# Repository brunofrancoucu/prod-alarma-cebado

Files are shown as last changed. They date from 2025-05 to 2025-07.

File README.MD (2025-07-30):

# Consigna
A nivel mundial, cerca de 100 millones de personas sufren de
deshidratación anualmente. Eso equivale a 3 personas por segundo!
Es nuestro deber recordar a la gente a mantenerse hidratada!

Objetivo: Hacer una alarma para tomar mate. Deben diseñar el esquemático y PCB (en KiCad), partiendo del circuito
dispuesto, y generar una bill of materials (BOM) completa.
# kicad - Esquematico y layout
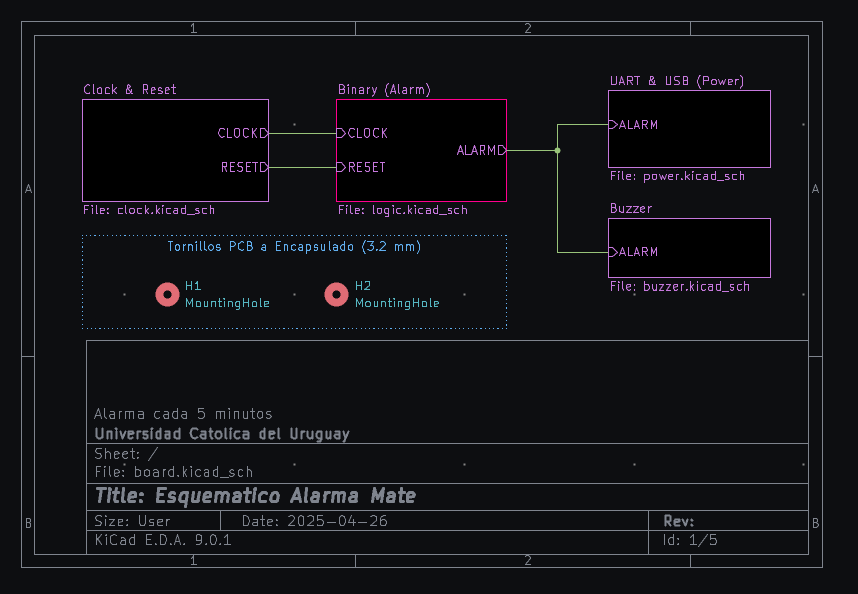
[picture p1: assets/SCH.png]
Stitching Capacitor

Proceso de diseno placa conexiones electricas entre componentes, alineado de componentes, soldadura y manejo en gral, medición de señales, eventuales hotfixes. 
[consideraciones](/board/README.MD), [calculos](/board/README.MD#calculos), [BOM](/BOM.html)
# Autodesk Inventor - Encapsulado
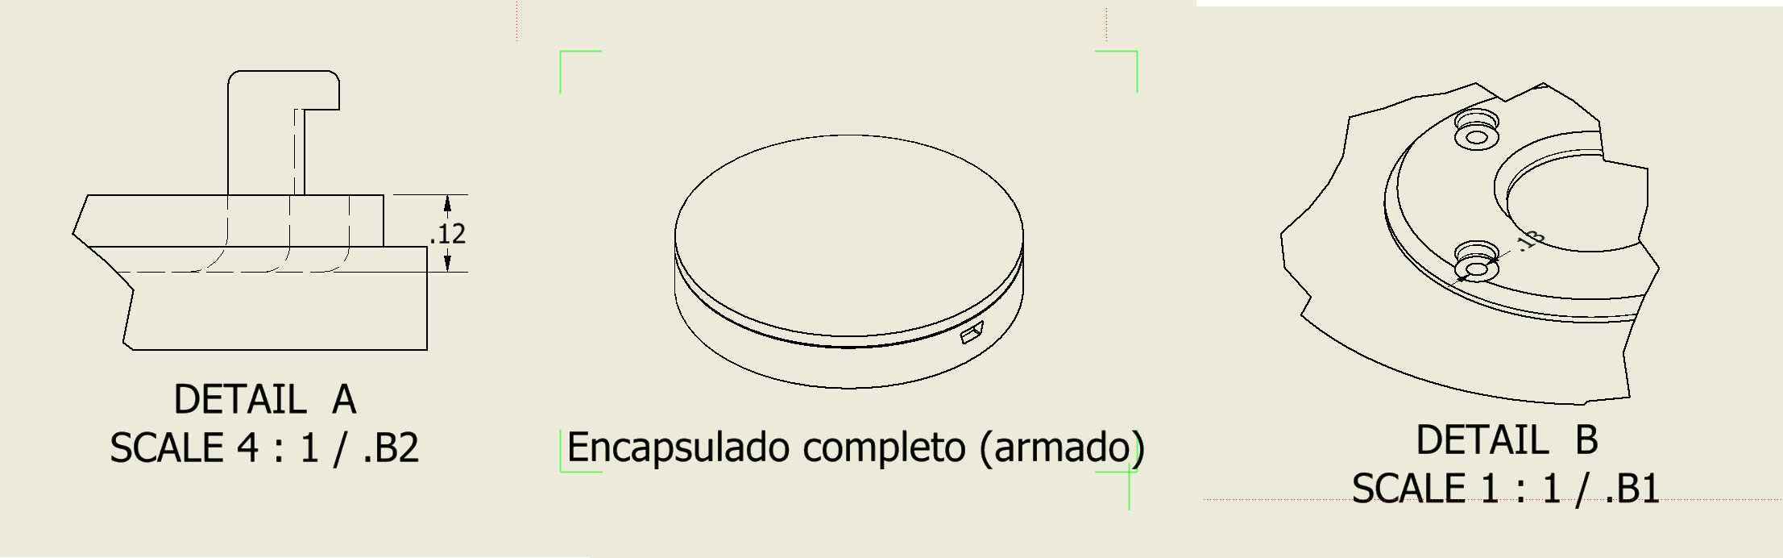
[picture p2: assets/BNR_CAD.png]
Int

Proceso de diseno del envolvente plastico
[consideraciones](/enclosure/README.md#consideraciones-housingipt)

# Producto Final
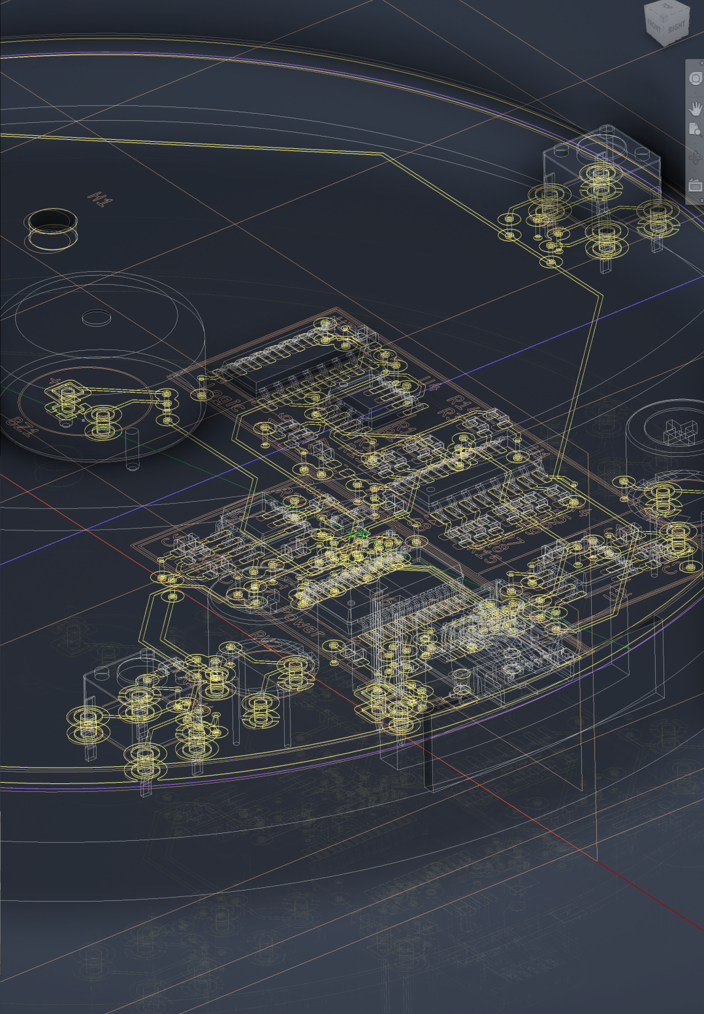
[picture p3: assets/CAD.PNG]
Foto


Feedback:
- Contra-peso [return force](https://www.digikey.com/en/products/detail/same-sky-formerly-cui-devices/TS02-66-90-BK-260-SCR-D/15634305) (btn push)
- USB-c
- Bateria (Conexion a placa)

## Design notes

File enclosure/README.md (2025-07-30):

Int

## Consideraciones `housing.ipt`
- Grosor 1.6 mm +-10% [4-layer PCB](https://www.pcbway.com/multi-layer-laminated-structure.html)
- Conector Ancho 6.9 mm, Alto 3.1 mm [USB](https://www.digikey.com/en/products/detail/same-sky-formerly-cui-devices/TS02-66-90-BK-260-SCR-D/15634305)
- Patas TH 0.5 mm [Buzzer](https://www.digikey.com/en/products/detail/soberton-inc/GT-0905A/1245335)
- Push travel 0.25 mm, Altura 9.0 mm [Actuador](https://www.digikey.com/en/products/detail/same-sky-formerly-cui-devices/TS02-66-90-BK-260-SCR-D/15634305)
- Peso de Plate, >0.2 N (x3) [Return Force](https://www.digikey.com/en/products/detail/same-sky-formerly-cui-devices/TS02-66-90-BK-260-SCR-D/15634305)

## Constrains de Altura
- Dado boton push de 9.0 mm (desde PCB)
- Plate con 3.0 mm (desde cara interior)
- Altura desde PCB del `housing` 6.0 mm 
- 2.0 mm enganche (riel) - 0.1 mm margen (impresion) - 0.2 mm push travel
- `housing` inferior, 3.0 mm (hasta PCB) + 1.6 mm PCB

## TODO
-Invertir enganche `plate` con `housing` (no expone interior en derrame)

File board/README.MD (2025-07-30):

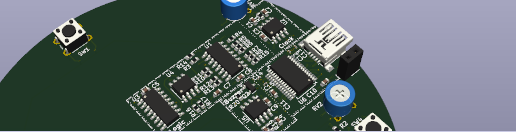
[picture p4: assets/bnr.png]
Int


# Ruteo de alta frecuencia con coupling a GND Y PWR
Par diferencial de alta frecuencia por multiples capas, respetando la impedancia el return path sera por PWR (debido a stack up intermedio de GND PWR y no GND GND), por ello utilizar capacitor en puntos de entrada (source) y salida (exit) (split boundary)

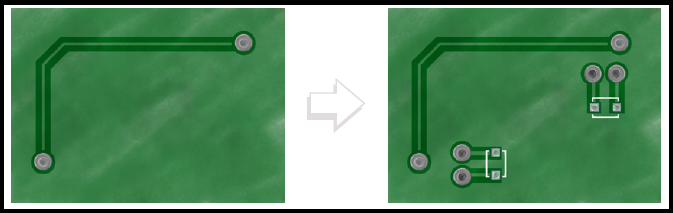
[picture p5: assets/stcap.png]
Stitching Capacitor


### Stitching capacitor:
[ref1](https://www.asset-intertech.com/wp-content/uploads/2020/05/6a01348365b3a6970c01b8d06c22f7970c-pi.jpg), [ref2](https://www.protoexpress.com/blog/wp-content/uploads/2020/05/28.png)
Valores normales para el stitching capacitor ronda los, 10nF and 100nF [src](https://www.protoexpress.com/blog/best-high-speed-pcb-routing-practices/)
Evitar: "If that plane is cut, the return current must detour—often radiating or coupling into other nets—and you’ll get reflections, EMI, and extra crosstalk" - gpt

# Calculos:
### Par diferencial:
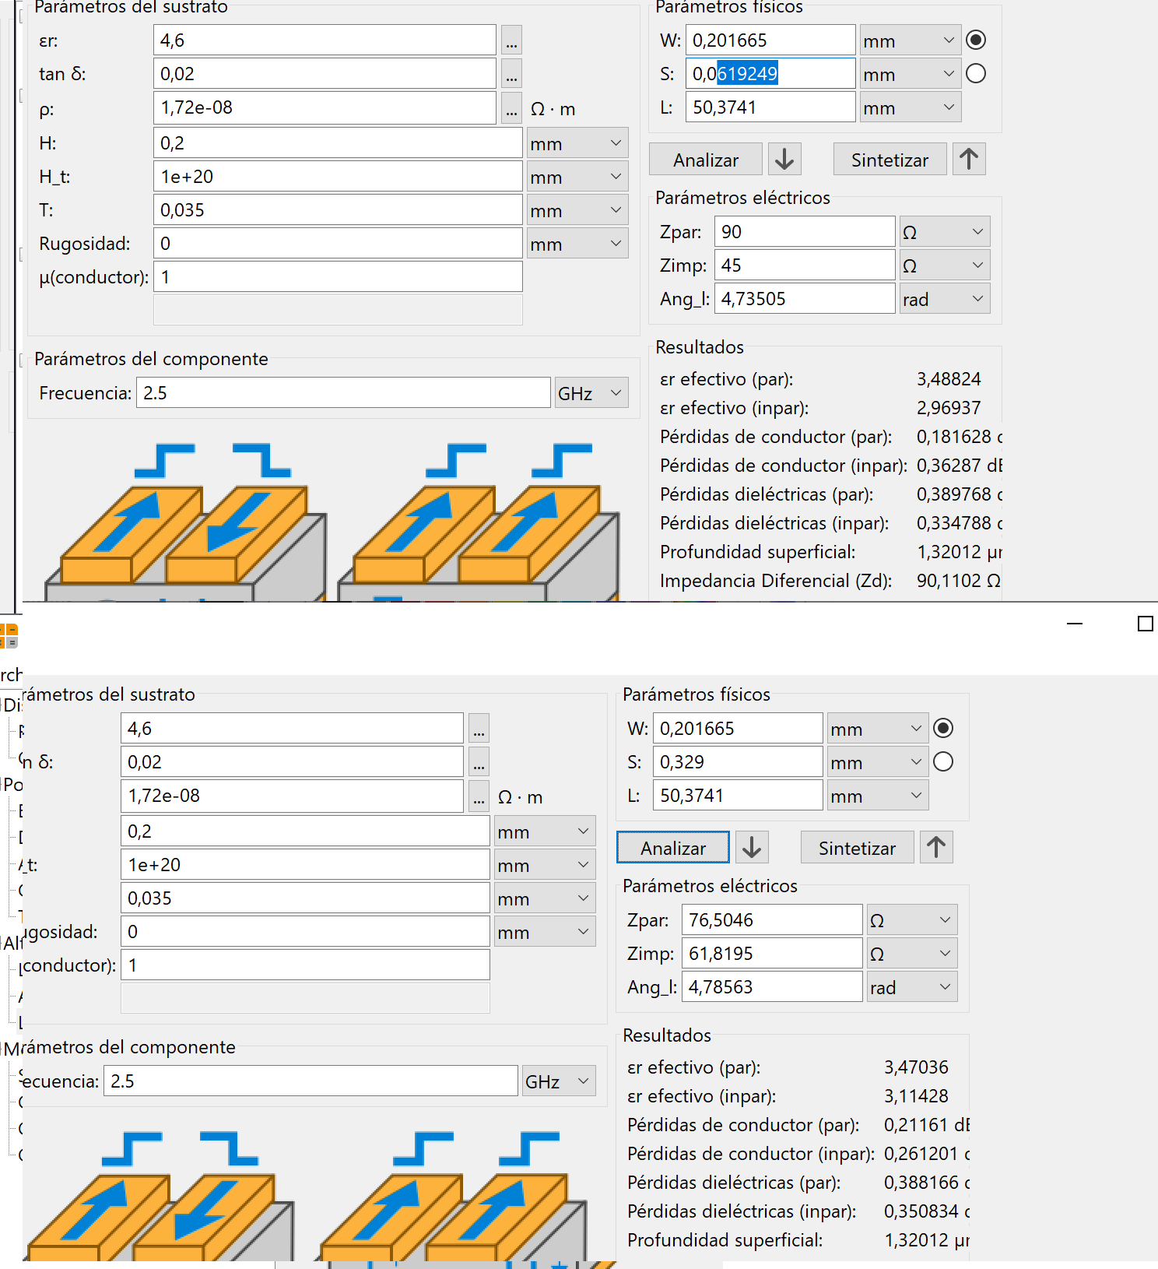
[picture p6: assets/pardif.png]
pardif

Z0: 90ohms +-15%
w: εᵣ 4.6 7628 prepreg FR-4 glass-epoxy laminate [ref](https://jlcpcb.com/capabilities/pcb-capabilities)
h: 0.2mm
Ancho pista: 0.202 mm - separacion pista recomendada: 0.062 mm, maxima: 0.329 mm

### Stitching capacitor, "capacitancia ideal":
Frequencia usb 3.0: 2.5 Ghz (medible con el "rise time" de la señal), entonces, para un Zdiff de 90 ohmios el Zbridge resulta 9 ohmios, capacitancia minima: 7.1 pF
- 100 nF 0402 or 0201	for low-frequency return (10 kHz – 100 MHz)	
- 1 nF 0201	covers 100 MHz – 1 GHz
- 100 pF 0201	covers 1 GHz – 3.5+ GHz (✔️ Recomendable)

Nos aseguramos: effective throughput (bit errors), calidad de señal compliance al USB.

# Complemento

### Recomendacion (plano de referencia limpio): SIG, GND, GND, (SIG + PWR)
Objetivo / desafio: mantener bajo cross talk con un coupling corto / cercano (usando PWR como plano de referencia)

### Otras alternativas:
- GND temporal en PWR (capa 3), justo arriba de par diferencial en la 4ta capa (SIG).
- Rutearlo por arriba.

# TODO
- Bateria Litio recargable
- Entrada USB-C
- Comunicacion puerto UART (notificacion escritorio)

## Gerbers
`File > Export > Fabrication Outputs > Gerbers`
1. `Generate Drill Files...` Gerber X2
2. RUN DRC...
3. Plot
4. Verificar en `Gerber View`

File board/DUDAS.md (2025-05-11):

# Dudas
## Que pasa si una corriente de PWR pasa por el mismo lugar del coupling de HF en PWR?
"The stitching capacitor gives the high-frequency return current a tiny, low-inductance bridge to ground while remaining invisible to the DC and low-frequency load currents on the power plane. Both currents can coexist on the same copper without interfering, provided you keep the plane wide and the decoupling network healthy"
superimpose - no problema, diferentes frequencias

## Como fluye la corriente de retorno si el capacitor bloquea DC?
appears as one continuous copper sheet plane
It’s not for power—it’s for fields
small capacitor’s reactance - planes shorted together
Because the capacitor sits directly beneath the pair and is very low-inductance, the loop area stays tiny and the differential-pair sees a continuous impedance environment.

source: https://www.protoexpress.com/blog/best-high-speed-pcb-routing-practices/

## Averiguar si podemos uasr un capacitor (menor inductancia) 0402 o ... 0201 (actual: protoexpress, 100nF)
"The best high-speed performances are usually accomplished if the component’s width is close to the track width. This will lower the impedance matching issues between the track and the component pad."
- protoexpress (11. Choose ...)
ideal: 100pF 0201

The differential pair itself doesn't require a ground, as it relies on the signal difference between the two traces, not a shared reference to ground. howeber

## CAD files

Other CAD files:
enclosure/Assembly.dwg
enclosure/OldVersions/Assembly.0001.dwg
enclosure/Assembly.iam
enclosure/OldVersions/Assembly.0002.iam
enclosure/OldVersions/housing.0010.ipt
enclosure/OldVersions/plate.0002.ipt
enclosure/board/board/Buzzer_15x7.5RM7.6.ipt
enclosure/board/board/C_0201_0603Metric.ipt
enclosure/board/board/C_0603_1608Metric.ipt
enclosure/board/board/OldVersions/pcb_board.0002.iam
enclosure/board/board/PinSocket_1x02_P2.54mm_Vertical.ipt
enclosure/board/board/Potentiometer_Bourns_3339P_Vertical.ipt
enclosure/board/board/R_0603_1608Metric.ipt
enclosure/board/board/SO-16_3.9x9.9mm_P1.27mm.ipt
enclosure/board/board/SOIC-8_3.9x4.9mm_P1.27mm.ipt
enclosure/board/board/SOT-23.ipt
enclosure/board/board/SSOP-28_5.3x10.2mm_P0.65mm.ipt
enclosure/board/board/SW_PUSH_6mm_H9.5mm.ipt
enclosure/board/board/USB_Mini-B_Lumberg_2486_01_Horizontal.ipt
enclosure/board/board/board.iam
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

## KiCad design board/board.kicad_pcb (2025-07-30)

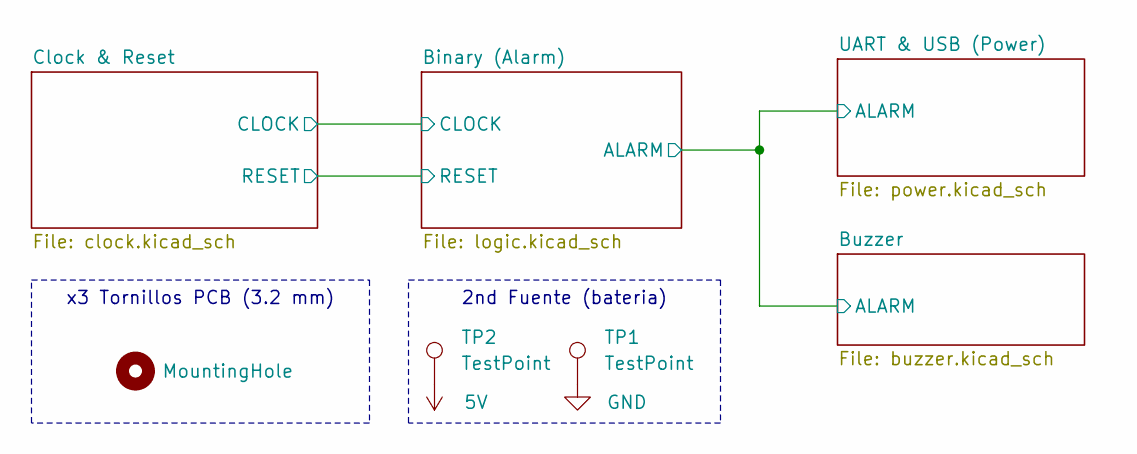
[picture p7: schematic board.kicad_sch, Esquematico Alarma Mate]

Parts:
H1: MountingHole; MountingHole_3.2mm_M3
TP1: TestPoint; TestPoint_THTPad_2.0x2.0mm_Drill1.0mm
TP2: TestPoint; TestPoint_THTPad_D2.0mm_Drill1.0mm

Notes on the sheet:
2nd Fuente (bateria)
x3 Tornillos PCB (3.2 mm)

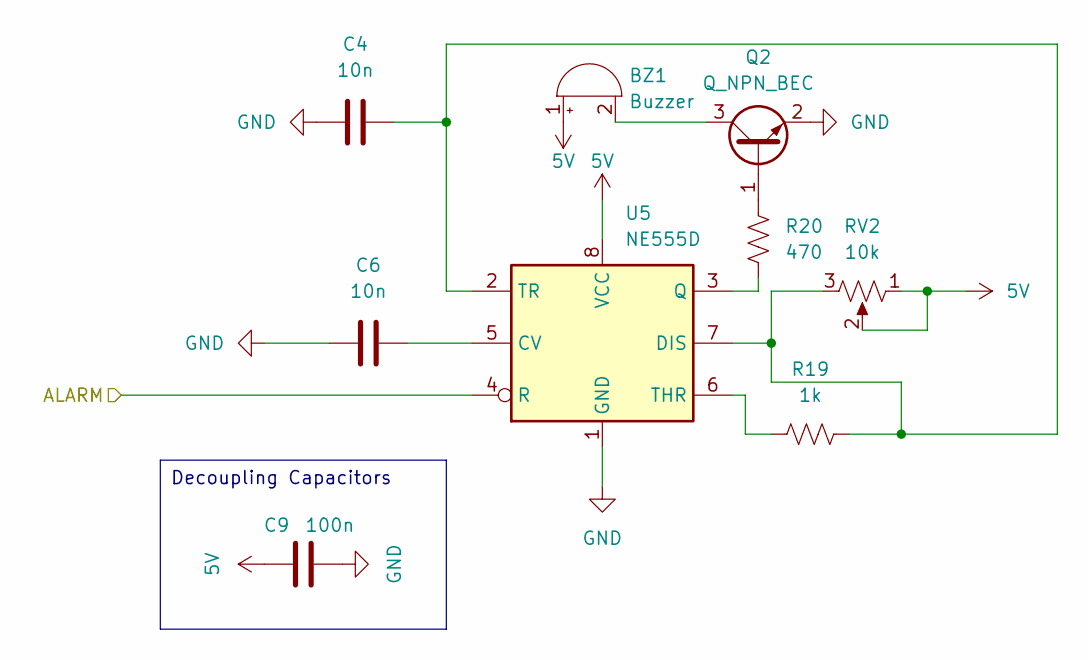
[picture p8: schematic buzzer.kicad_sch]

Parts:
BZ1: Buzzer; MagneticBuzzer_PUI_AT-0927-TT-6-R
C4, C6: 10n; C_0603_1608Metric
C9: 100n; C_0603_1608Metric
Q2: Q_NPN_BEC; SOT-23
R19: 1k; R_0603_1608Metric
R20: 470; R_0603_1608Metric
RV2: 10k; Potentiometer_Piher_PT-6-V_Vertical
U5: NE555D; SOIC-8_3.9x4.9mm_P1.27mm

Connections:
5V: BZ1.1 (+), C9.1, RV2.1, RV2.2, U5.8 (VCC); also elsewhere on the board
ALARM: U5.4 (R); also elsewhere on the board
GND: C4.2, C6.1, C9.2, Q2.2 (E), U5.1 (GND); also elsewhere on the board
unnamed: BZ1.2 (-), Q2.3 (C)
unnamed: Q2.1 (B), R20.1
unnamed: C6.2, U5.5 (CV)
unnamed: C4.1, R19.1, RV2.3, U5.2 (TR), U5.7 (DIS)
unnamed: R20.2, U5.3 (Q)
unnamed: R19.2, U5.6 (THR)

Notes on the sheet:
Decoupling Capacitors

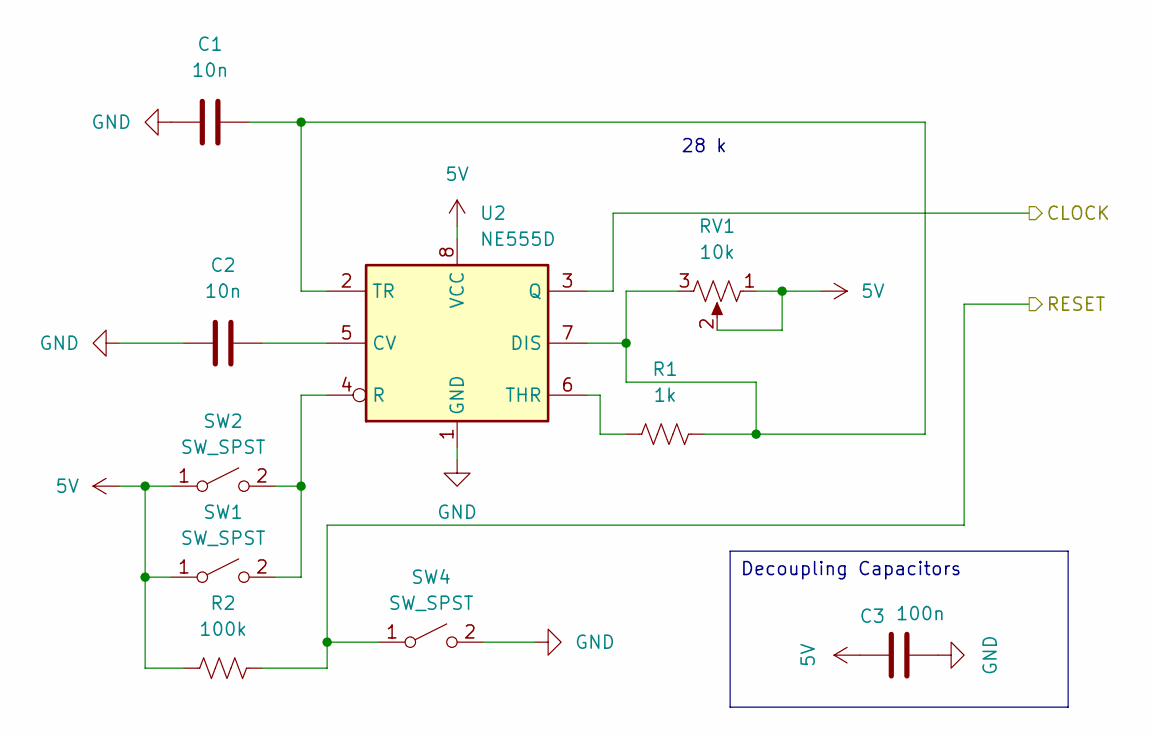
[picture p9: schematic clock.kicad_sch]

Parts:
C1, C2: 10n; C_0603_1608Metric
C3: 100n; C_0603_1608Metric
R1: 1k; R_0603_1608Metric
R2: 100k; R_0603_1608Metric
RV1: 10k; Potentiometer_Piher_PT-6-V_Vertical
SW1, SW2, SW4: SW_SPST; SW_PUSH_6mm_H4.3mm
U2: NE555D; SOIC-8_3.9x4.9mm_P1.27mm

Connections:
5V: C3.1, R2.1, RV1.1, RV1.2, SW1.1 (A), SW2.1 (A), U2.8 (VCC); also elsewhere on the board
CLOCK: U2.3 (Q); also elsewhere on the board
GND: C1.2, C2.1, C3.2, SW4.2 (B), U2.1 (GND); also elsewhere on the board
unnamed: SW1.2 (B), SW2.2 (B), U2.4 (R)
unnamed: C2.2, U2.5 (CV)
unnamed: C1.1, R1.1, RV1.3, U2.2 (TR), U2.7 (DIS)
unnamed: R1.2, U2.6 (THR)
RESET: R2.2, SW4.1 (A); also elsewhere on the board

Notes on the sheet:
28 k
Decoupling Capacitors

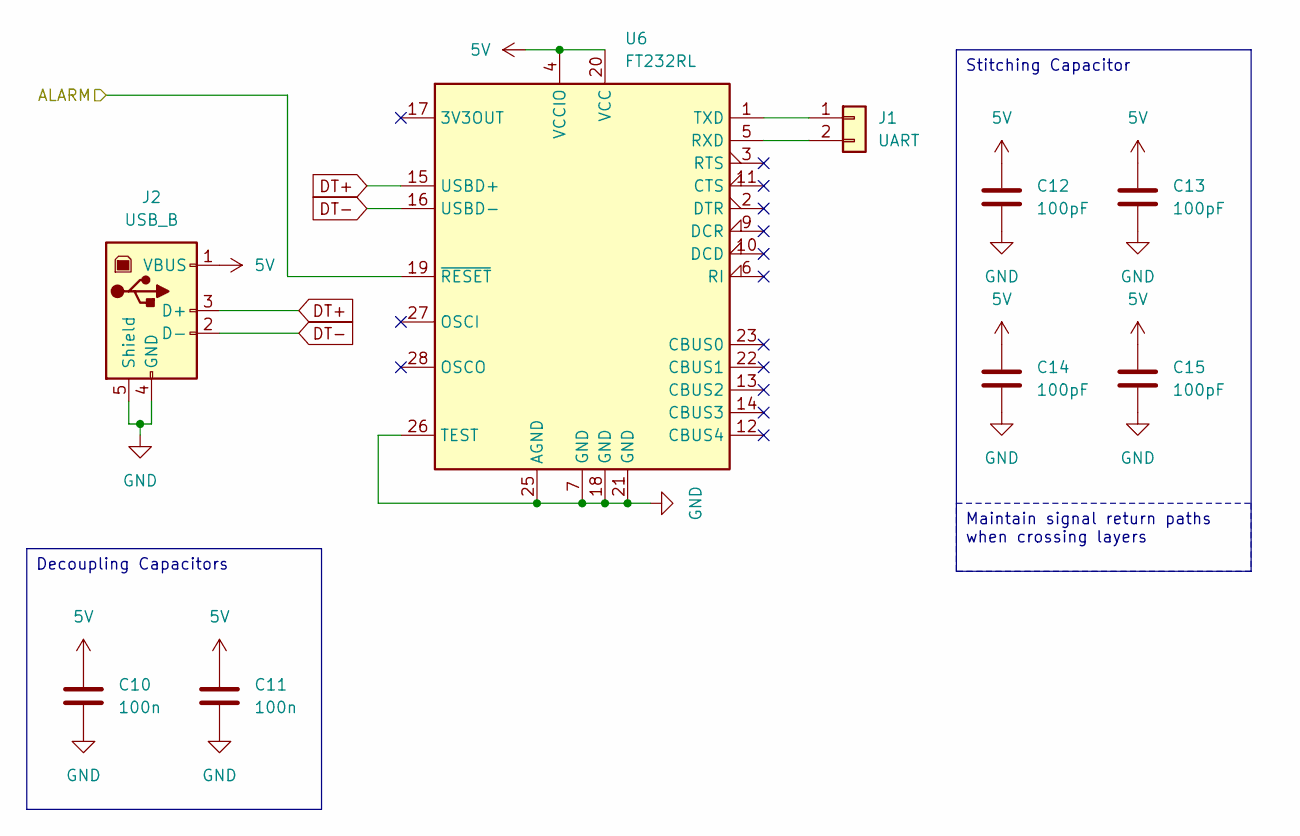
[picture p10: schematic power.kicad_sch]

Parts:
C10, C11: 100n; C_0603_1608Metric
C12, C13, C14, C15: 100pF; C_0201_0603Metric
J1: UART; PinSocket_1x02_P2.54mm_Vertical
J2: USB_B; USB_Mini-B_Lumberg_2486_01_Horizontal
U6: FT232RL; SSOP-28_5.3x10.2mm_P0.65mm

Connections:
5V: C10.1, C11.1, C12.1, C13.1, C14.1, C15.1, J2.1 (VBUS), U6.4 (VCCIO), U6.20 (VCC); also elsewhere on the board
ALARM: U6.19 (~RESET); also elsewhere on the board
DT+: J2.3 (D+), U6.15 (USBD+)
DT-: J2.2 (D-), U6.16 (USBD-)
GND: C10.2, C11.2, C12.2, C13.2, C14.2, C15.2, J2.4 (GND), J2.5 (Shield), U6.7 (GND), U6.18 (GND), U6.21 (GND), U6.25 (AGND), U6.26 (TEST); also elsewhere on the board
unnamed: J1.1, U6.1 (TXD)
unnamed: J1.2, U6.5 (RXD)

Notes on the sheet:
Stitching Capacitor
Maintain signal return paths when crossing layers
Decoupling Capacitors

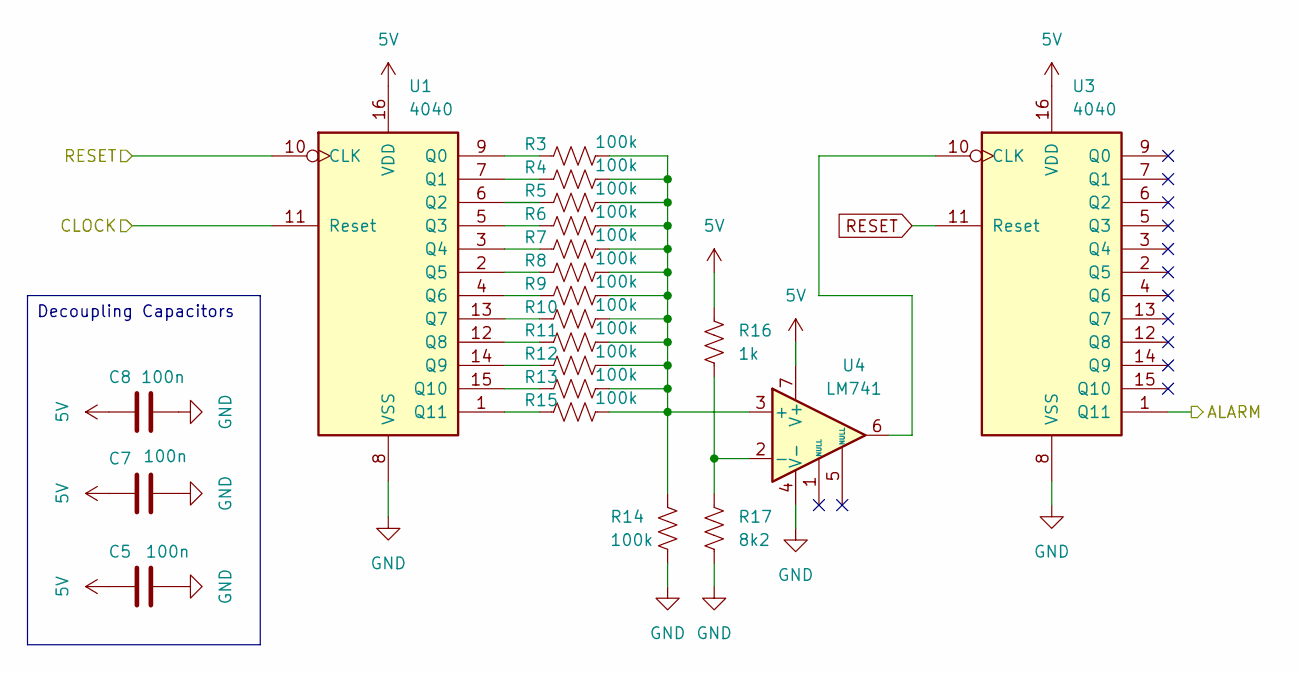
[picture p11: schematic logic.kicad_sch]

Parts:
C5, C7, C8: 100n; C_0603_1608Metric
R3, R4, R5, R6, R7, R8, R9, R10, R11, R12, R13, R14, R15: 100k; R_0603_1608Metric
R16: 1k; R_0603_1608Metric
R17: 8k2; R_0603_1608Metric
U1, U3: 4040; SO-16_3.9x9.9mm_P1.27mm
U4: LM741; SOIC-8_3.9x4.9mm_P1.27mm

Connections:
5V: C5.1, C7.1, C8.1, R16.2, U1.16 (VDD), U3.16 (VDD), U4.7 (V+); also elsewhere on the board
ALARM: U3.1 (Q11); also elsewhere on the board
CLOCK: U1.10 (CLK); also elsewhere on the board
GND: C5.2, C7.2, C8.2, R14.1, R17.1, U1.8 (VSS), U3.8 (VSS), U4.4 (V-); also elsewhere on the board
unnamed: R3.1, U1.9 (Q0)
unnamed: R4.1, U1.7 (Q1)
unnamed: R5.1, U1.6 (Q2)
unnamed: R6.1, U1.5 (Q3)
unnamed: R7.1, U1.3 (Q4)
unnamed: R8.1, U1.2 (Q5)
unnamed: R9.1, U1.4 (Q6)
unnamed: R10.1, U1.13 (Q7)
unnamed: R11.1, U1.12 (Q8)
unnamed: R12.1, U1.14 (Q9)
unnamed: R13.1, U1.15 (Q10)
unnamed: R15.1, U1.1 (Q11)
unnamed: U3.10 (CLK), U4.6
unnamed: R3.2, R4.2, R5.2, R6.2, R7.2, R8.2, R9.2, R10.2, R11.2, R12.2, R13.2, R14.2, R15.2, U4.3 (+)
unnamed: R16.1, R17.2, U4.2 (-)
RESET: U1.11 (Reset), U3.11 (Reset); also elsewhere on the board

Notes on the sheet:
Decoupling Capacitors

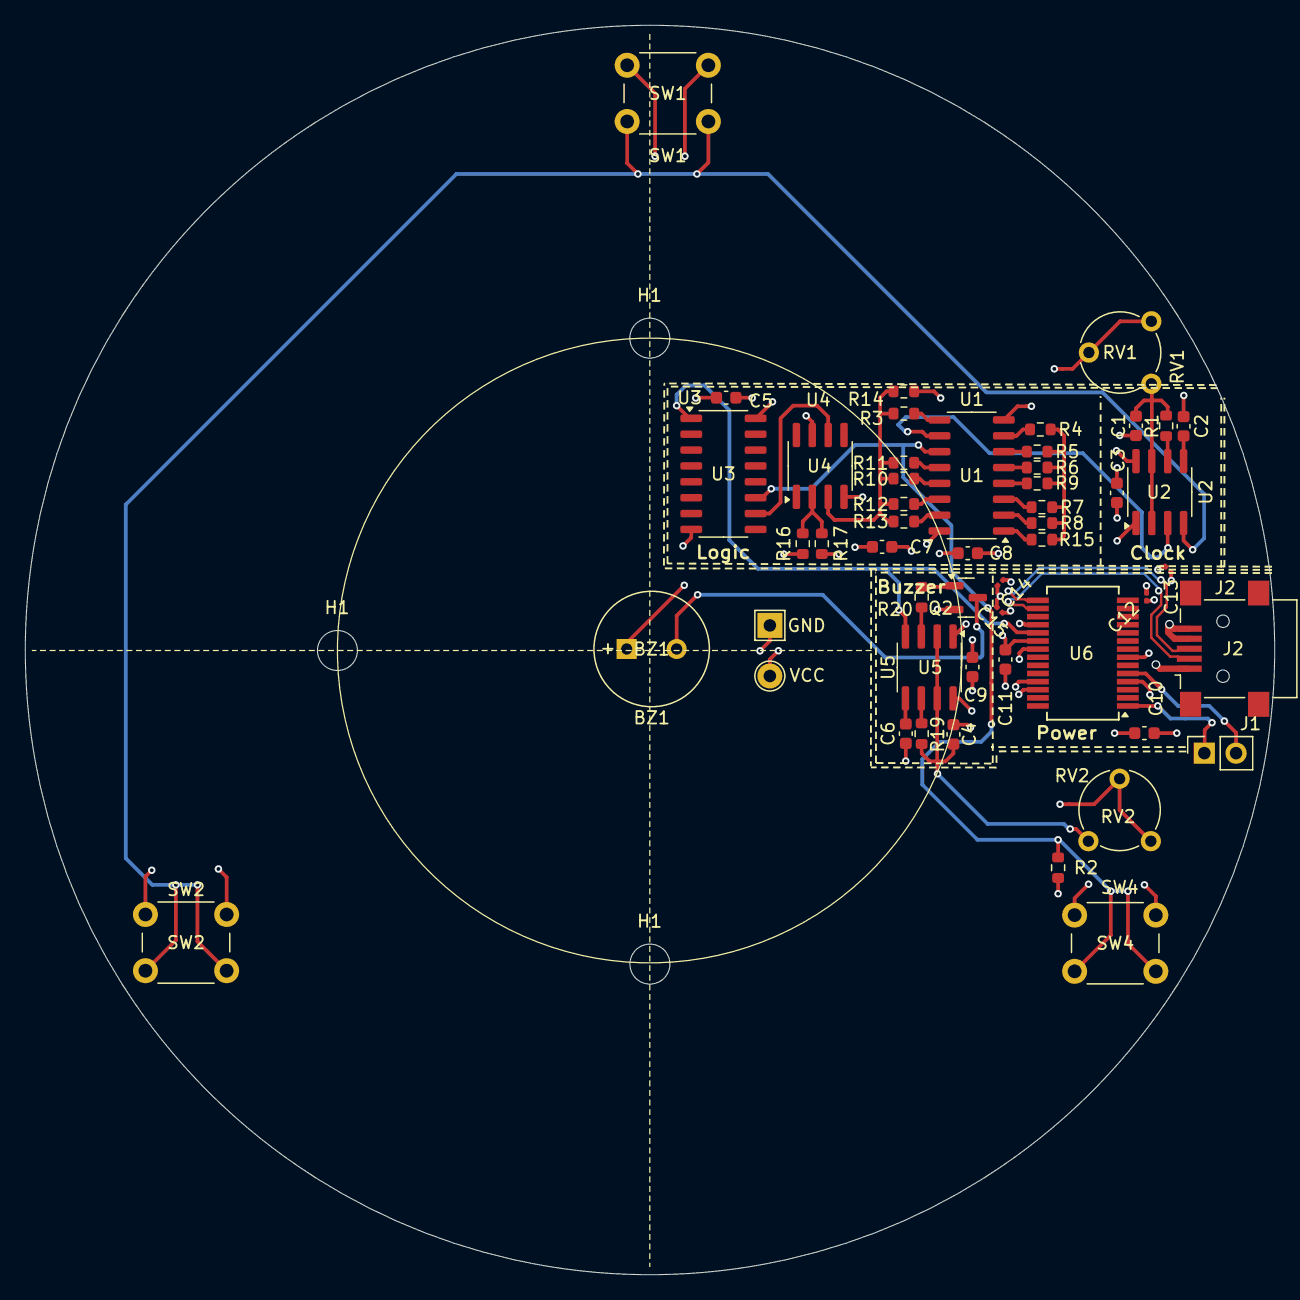
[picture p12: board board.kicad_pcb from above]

Board: 4 copper layers, 100.0 x 100.0 mm, 54 parts (0 on the bottom side), 34 nets.

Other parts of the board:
GND: TestPoint; TestPoint_THTPad_2.0x2.0mm_Drill1.0mm
H1#2, H1#3: MountingHole; MountingHole_3.2mm_M3
VCC: TestPoint; TestPoint_THTPad_D2.0mm_Drill1.0mm

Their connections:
5V: VCC.1; also elsewhere on the board
GND: GND.1; also elsewhere on the board

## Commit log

2025-07-23 refactor: moved to board
    [and.kicad_sch, buzzer.kicad_sch, clock.kicad_sch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]
2025-07-23 add: layout, gerbers
    [queremate.kicad_pcb, queremate.kicad_sch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]
2025-07-23 refactor: renamed
    [board.kicad_pcb, board.kicad_sch]
2025-07-23 add: missing files
    [buzzer.kicad_sch, clock.kicad_sch, logic.kicad_sch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]
2025-07-23 add: vias through - fix: routes
    [board.kicad_pcb]
2025-07-23 add: stitching capacitor & gerbers
    [board-B_Mask.gbr, board-B_Paste.gbr, board-B_SGN.gbr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]
2025-07-27 add: Hierarchical Sheets
    [board.kicad_sch, buzzer.kicad_sch, clock.kicad_sch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]
2025-07-27 add: Mounting holes, box comments
    [board.kicad_sch, buzzer.kicad_sch, clock.kicad_sch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]
2025-07-27 add: pcb layout & gerbers
    [board-B_Mask.gbr, board-B_Paste.gbr, board-B_SGN.gbr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]
2025-07-28 add: Referencias en Silkscreen centradas al componente
    [board.kicad_pcb]
2025-07-28 add: 3 mechanical holes & .step 3d
    [board.kicad_pcb]
2025-07-29 add: product enclosure
    [housing.0009.ipt, housing.ipt, pcb_Buzzer_15x7.5RM7.6.ipt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]
2025-07-30 add: 9mm 3d push btn, VCC GND pins (battery)
    [board.kicad_pcb, board.kicad_sch]
2025-07-30 add: rectangle TIP GNS
    [board.kicad_pcb, board.kicad_sch]
2025-07-30 add: hosuing & plate (latest)
    [Assembly.0001.iam, Assembly.iam, Buzzer_15x7.5RM7.6.ipt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]
2025-07-30 doc: CAD
    [Assembly.0001.dwg, Assembly.dwg]
2025-07-30 add: cover motion constrain
    [Assembly.0001.iam, Assembly.0002.iam, Assembly.iam]
